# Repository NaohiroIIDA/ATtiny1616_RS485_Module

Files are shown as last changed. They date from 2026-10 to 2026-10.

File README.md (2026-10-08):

# ATtiny1616_RS485_Module

ATtiny1616マイコンとRS485トランシーバを搭載した小型の基板モジュールです。

## 概要

ATtiny1616とRS485トランシーバ（H485EIDQ）を13×22mmの基板に載せたモジュールです。
4ピンのJST SHコネクタで、複数台をRS485バスに数珠つなぎにできます。
空いているGPIOはすべて2.54mmピッチのピンヘッダに出してあります。

- **MCU**: ATtiny1616-MNR（QFN-20、tinyAVR 1-series）
- **通信**: RS485（半二重）
- **設計ツール**: EasyEDA Pro

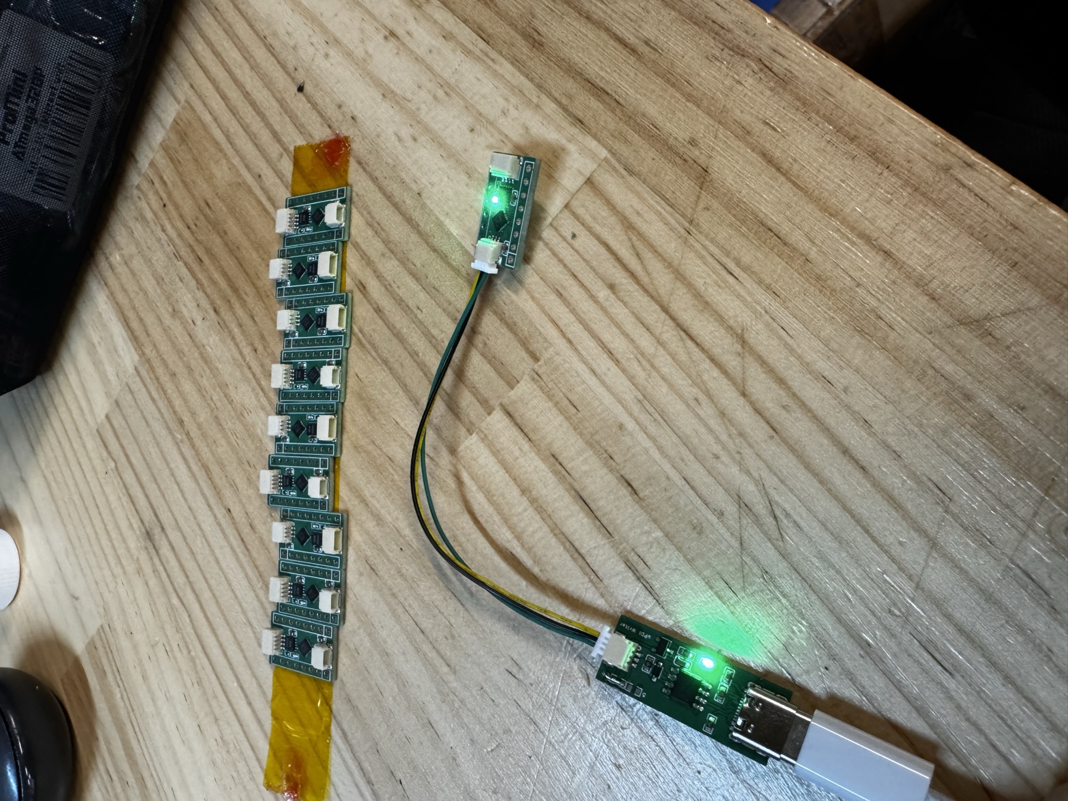
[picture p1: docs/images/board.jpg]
ATtiny1616 RS485 Module


*左：組み立て済みの基板。右：UPDIライタにつないで書き込んでいるところ*

## ハードウェア仕様

| 項目 | 内容 |
|---|---|
| MCU | ATtiny1616-MNR |
| RS485トランシーバ | H485EIDQ/TR（DFN-8） |
| 電源電圧 | 5V |
| 終端抵抗 | 120Ω（R6、裏面。標準では未実装） |
| 基板サイズ | 約13.2×21.8mm |
| RS485コネクタ | JST SM04B-SRSS-TB（SH 1.0mm 4ピン）。表面のU6と、裏面のU11（標準では未実装） |
| 書込みコネクタ | JST SM03B-SRSS-TB（SH 1.0mm 3ピン、UPDI）（U9） |
| GPIO | 2.54mmピッチ 8ピンヘッダ×2（H1・H2） |
| 状態LED | PB0（1kΩ経由、Highで点灯） |

### 裏面部品の実装（R6・U11）

裏面のR6（120Ω終端抵抗）とU11（2つ目のRS485コネクタ）は標準では未実装です。バス上のどこに置くかで、どちらか一方を実装します。

| 位置 | 実装する部品 |
|---|---|
| バスの末端 | R6（120Ω終端抵抗） |
| バスの途中（次のデバイスへつなぐ） | U11（コネクタ） |

```
[マスター]──U6[モジュール]U11──U6[モジュール]U11──U6[モジュール]R6
              （途中）              （途中）              （末端）
```

### MCUのピン割り当て

| ATtiny1616 | 機能 |
|---|---|
| PB2（TXD） | RS485 DI（送信） |
| PB3（RXD） | RS485 RO（受信） |
| PB4 | RS485 DE / RE#（送信イネーブル。Highで送信） |
| PB0 | LED（Highで点灯） |
| PA0 | UPDI |

RS485にはUSART0のデフォルトピン（PB2/PB3）を使っています。

### ピン一覧（Arduinoピン番号と周辺機能）

Arduinoピン番号はmegaTinyCoreの番号です。コードでは `PIN_PB0` のようにポート名で書くと、番号の取り違えを防げます。

| ピン | Arduino番号 | 基板での用途 | 主な周辺機能 |
|---|---|---|---|
| PA4 | 0 | H1-3 | ADC0 AIN4、SPI SS、PWM |
| PA5 | 1 | H1-4 | ADC0 AIN5、PWM |
| PA6 | 2 | H1-5 | ADC0 AIN6 |
| PA7 | 3 | H1-6 | ADC0 AIN7 |
| PB5 | 4 | H1-7 | ADC0 AIN8 |
| PB4 | 5 | RS485 DE / RE# | （使用中） |
| PB3 | 6 | RS485 RO | USART0 RX（使用中） |
| PB2 | 7 | RS485 DI | USART0 TX（使用中） |
| PB1 | 8 | H1-8 | ADC0 AIN10、I2C SDA（標準）、PWM |
| PB0 | 9 | LED | I2C SCL（標準）（LEDで使用中） |
| PC0 | 10 | H2-8 | SPI SCK（代替）、PWM |
| PC1 | 11 | H2-7 | SPI MISO（代替）、PWM |
| PC2 | 12 | H2-6 | SPI MOSI（代替） |
| PC3 | 13 | H2-5 | SPI SS（代替） |
| PA1 | 14 | H2-3 | ADC0 AIN1、SPI MOSI（標準）、I2C SDA（代替） |
| PA2 | 15 | H2-2 | ADC0 AIN2、SPI MISO（標準）、I2C SCL（代替） |
| PA3 | 16 | H2-1 | ADC0 AIN3、SPI SCK（標準）、PWM |
| PA0 | 17 | UPDI | （書き込み専用） |

PWMはmegaTinyCoreの標準設定で `analogWrite()` が使えるピンです。詳細はATtiny1616のデータシートで確認してください。

> **I2Cを使うときの注意**：I2C（TWI0）の標準ピンはSCL=PB0、SDA=PB1ですが、PB0はLEDにつながっています。I2Cは代替ピン（SCL=PA2、SDA=PA1）に切り替えて使ってください。megaTinyCoreでは `Wire.swap(1);` を `Wire.begin()` の前に呼びます。

### コネクタ

**RS485（U6・U11、2つとも同じピン配置）**

| ピン | 信号 |
|---|---|
| 1 | VCC |
| 2 | A |
| 3 | B |
| 4 | GND |

**UPDI（U9）**

| ピン | 信号 |
|---|---|
| 1 | UPDI |
| 2 | GND |
| 3 | VCC |

**H1**

| ピン | 1 | 2 | 3 | 4 | 5 | 6 | 7 | 8 |
|---|---|---|---|---|---|---|---|---|
| 信号 | GND | VCC | PA4 | PA5 | PA6 | PA7 | PB5 | PB1 |

**H2**

| ピン | 1 | 2 | 3 | 4 | 5 | 6 | 7 | 8 |
|---|---|---|---|---|---|---|---|---|
| 信号 | PA3 | PA2 | PA1 | UPDI | PC3 | PC2 | PC1 | PC0 |

## ファームウェア開発

| 項目 | 内容 |
|---|---|
| 開発環境 | PlatformIO（platform: `atmelmegaavr`、framework: `arduino`。コアはmegaTinyCore） |
| クロック | 20MHz（内部オシレータ。ヒューズOSCCFG=0x02） |
| 書き込み | SerialUPDI（U9コネクタ、57600bps） |

サンプル：

- [firmware/Blink_led](firmware/Blink_led)：状態LEDの点滅。新しいプロジェクトの雛形としても使えます

```bash
cd firmware/Blink_led
pio run                                                  # ビルド
pio run -t fuses  --upload-port /dev/cu.usbserial-XXXX   # ヒューズ書き込み（初回のみ）
pio run -t upload --upload-port /dev/cu.usbserial-XXXX   # 書き込み
```

ポート名は `pio device list` で確認できます。ヒューズを書き込まないと出荷時設定（16MHz）のまま動き、時間がずれます。

### ヒューズ設定

| ヒューズ | 値 | 内容 |
|---|---|---|
| WDTCFG（FUSE0） | 0x00 | ウォッチドッグ無効 |
| BODCFG（FUSE1） | 0x00 | BOD無効 |
| OSCCFG（FUSE2） | 0x02 | 20MHz |
| SYSCFG0（FUSE5） | 0xC4 | CRC無効、PA0=UPDI、チップ消去でEEPROMも消去 |
| SYSCFG1（FUSE6） | 0x06 | 起動待機時間 8ms |
| APPEND（FUSE7） | 0x00 | アプリ領域制限なし |
| BOOTEND（FUSE8） | 0x00 | ブートセクションなし |

> **警告**：SYSCFG0のRSTPINCFGを変更しないでください（例：`0xC8`）。PA0がUPDIからRESETや GPIOに切り替わり、通常のUPDIライタでは二度と書き込めなくなります。復旧には12V対応の高電圧UPDIライタが必要です。

## リポジトリ構成

```
hardware/
  schematic/   回路図（PDF）
  pcb/         EasyEDA Proプロジェクト（.epro2）、PCB図面
  gerber/      製造用Gerberファイル
  bom/         部品表（BOM）、部品配置（CPL）
  3d/          3Dモデル（STEP）
firmware/      サンプルファームウェア
docs/          ドキュメント、写真
```

## 基板データ

| ファイル | 置き場所 |
|---|---|
| 回路図PDF | `hardware/schematic/` |
| PCB図面PDF | `hardware/pcb/` |
| EasyEDA Proプロジェクト（.epro2） | `hardware/pcb/` |
| Gerber（zip） | `hardware/gerber/` |
| BOM（xlsx・csv） | `hardware/bom/` |
| 3Dモデル（STEP） | `hardware/3d/` |

.epro2は、EasyEDA Proの「ファイル → インポート」で開けます。

## 使用例

このモジュールは以下のプロジェクトで使っています。

- [KER_TLE_V3_Module](https://github.com/NaohiroIIDA/KER_TLE_V3_Module)：TLE5012B磁気角度センサーモジュール

## ライセンス

[MIT License](LICENSE)

回路図・基板データ・ファームウェアを含め、このリポジトリのすべてのファイルが対象です。著作権表示を残せば、商用・非商用を問わず自由に使用・改変・再配布できます。

## 作者

Naohiro IIDA

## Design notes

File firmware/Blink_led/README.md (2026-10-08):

# Blink_led

ATtiny1616 RS485モジュールの状態LED（PB0）を500ms間隔で点滅させるサンプルです。
RS485のDE/RE#（PB4）はLowにして、バスを駆動しないようにしています。

## ビルドと書き込み

このフォルダ（`firmware/Blink_led`）で実行します。

```bash
# ビルド
pio run

# ヒューズ書き込み（20MHz設定など。初回のみ）
pio run -t fuses --upload-port /dev/cu.usbserial-120

# 書き込み
pio run -t upload --upload-port /dev/cu.usbserial-120
```

ポート名は `pio device list` で確認してください（Windowsなら `COM4` など）。
書き込みはSerialUPDI（U9コネクタ）で行います。

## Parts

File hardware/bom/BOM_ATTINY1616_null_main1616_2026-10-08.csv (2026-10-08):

No. | Quantity | Comment | Designator | Footprint | Value | Manufacturer Part | Manufacturer | Supplier Part | Supplier
1 | 2 | 100nF | C1,C2 | C0603 | 100nF | CC0603KRX7R9BB104 | YAGEO(国巨) | C14663 | LCSC
2 | 2 | PZ254V-11-08P | H1,H2 | HDR-TH_8P-P2.54-V-M |  | PZ254V-11-08P | XFCN(兴飞) | C492407 | LCSC
3 | 1 | F.0402.00001/P2-0402G1TS2-045T-001 | LED1 | LED0402-R-RD_GREEN |  | F.0402.00001/P2-0402G1TS2-045T-001 | TUOZHAN(拓展光电) | C7496801 | LCSC
4 | 1 | 1kΩ | R5 | R0402 | 1kΩ | 0402WGF1001TCE | UNI-ROYAL(厚声) | C11702 | LCSC
5 | 1 | 120 | R6 | R0603 | 120
6 | 1 | ATTINY1616-MNR | U4 | QFN-20_L3.0-W3.0-P0.40-BL-EP1.7 |  | ATTINY1616-MNR | MICROCHIP(美国微芯) | C507118 | LCSC
7 | 2 | SM04B-SRSS-TB(LF)(SN) | U6,U11 | CONN-SMD_4P-P1.00_SM04B-SRSS-TB-LF-SN |  | SM04B-SRSS-TB(LF)(SN) | JST | C160404 | LCSC
8 | 1 | SM03B-SRSS-TB(LF)(SN) | U9 | CONN-SMD_SM03B-SRSS-TB-LF-SN-P |  | SM03B-SRSS-TB(LF)(SN) | JST | C160403 | LCSC
9 | 1 | H485EIDQ/TR | U10 | DFN-8_L3.0-W3.0-P0.65-BL-EP2.2 |  | H485EIDQ/TR | HGSEMI(华冠) | C46552321 | LCSC

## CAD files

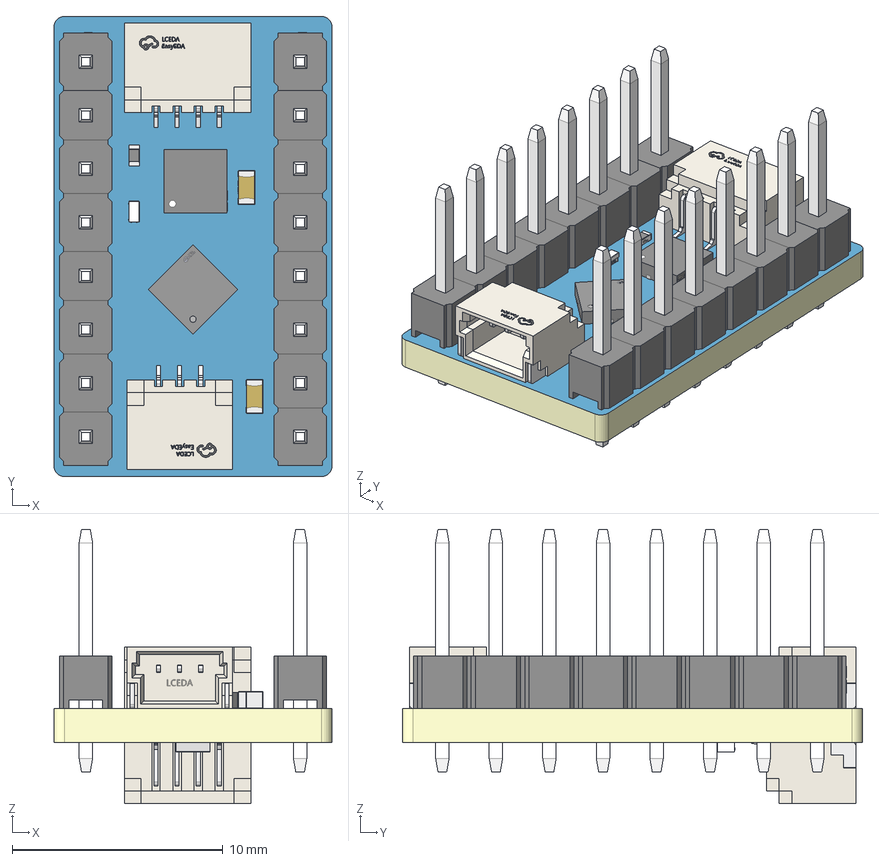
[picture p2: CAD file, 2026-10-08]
hardware/3d/3D_PCB9_2026-10-08.step
13.2 x 21.8 x 13.0 mm
Board~mkLh
TopCopper~mkLh
BottomCopper~mkLh
TopSilkscreen~mkLh
BottomSilkscreen~mkLh
TopFpcStiffener~mkLh
BottomFpcStiffener~mkLh
R0402~R0402_L1.0-W0.5-H0.4~IAVS
C0603~C0603_L1.6-W0.8-H0.8~PEQx x 2
CONN-SMD_4P-P1.00_SM04B-SRSS-TB-LF-SN~CONN-SMD_SR1.00-WS-4P~b4fu x 2
R0603~R0603~KfRT
HDR-TH_8P-P2.54-V-M~HDR-TH_8P-P2.54-V-M~K4U0 x 2
CONN-SMD_SM03B-SRSS-TB-LF-SN-P~CONN-SMD_SR1.00-WS-3P~Nkpu
DFN-8_L3.0-W3.0-P0.65-BL-EP2.2~DFN-8_L3.0-W3.0-P0.65-BL-EP2.2~bgaz
QFN-20_L3.0-W3.0-P0.40-BL-EP1.7~QFN-20_L3.0-W3.0-P0.40-BL-EP1.7~nTAD
LED0402-R-RD_GREEN~LED0402-R-RD_GREEN~S2Qn

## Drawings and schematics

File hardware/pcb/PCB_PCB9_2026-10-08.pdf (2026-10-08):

No. | Quantity | Comment | Designator | Footprint | Value | Manufacturer Part | Manufacturer | Supplier Part | Supplier
1 | 2 | 100nF | C1,C2 | C0603 | 100nF | CC0603KRX 7R9BB104 | YAGEO(国巨 ) | C14663 | LCSC
2 | 2 | PZ254V-11-0 8P | H1,H2 | HDR-TH_8P-P2.54-V-M | | PZ254V-11-0 8P | XFCN(兴飞 ) | C492407 | LCSC
3 | 1 | F.0402.0000 1/P2-0402G1 TS2-045T-00 1 | LED1 | LED0402-R-RD_GREEN | | F.0402.0000 1/P2-0402G1 TS2-045T-00 1 | TUOZHAN( 拓展光电 ) | C7496801 | LCSC
4 | 1 | 1k | R5 | R0402 | 1k | 0402WGF10 01TCE | UNI-ROYAL( 厚声 ) | C11702 | LCSC
5 | 1 | 120 | R6 | R0603 | 120
6 | 1 | ATTINY1616 -MNR | U4 | QFN-20_L3.0 -W3.0-P0.40-BL-EP1.7 | | ATTINY1616 -MNR | MICROCHIP( 美国微芯 ) | C507118 | LCSC
7 | 2 | SM04B-SRS S-TB(LF)(SN ) | U6,U11 | CONN-SMD_ 4P-P1.00_S M04B-SRSS-TB-LF-SN | | SM04B-SRS S-TB(LF)(SN ) | JST | C160404 | LCSC
8 | 1 | SM03B-SRS S-TB(LF)(SN ) | U9 | CONN-SMD_ SM03B-SRS S-TB-LF-SN- P | | SM03B-SRS S-TB(LF)(SN ) | JST | C160403 | LCSC
9 | 1 | H485EIDQ/T R | U10 | DFN-8_L3.0-W3.0-P0.65-BL-EP2.2 | | H485EIDQ/T R | HGSEMI( 华 冠 ) | C46552321 | LCSC

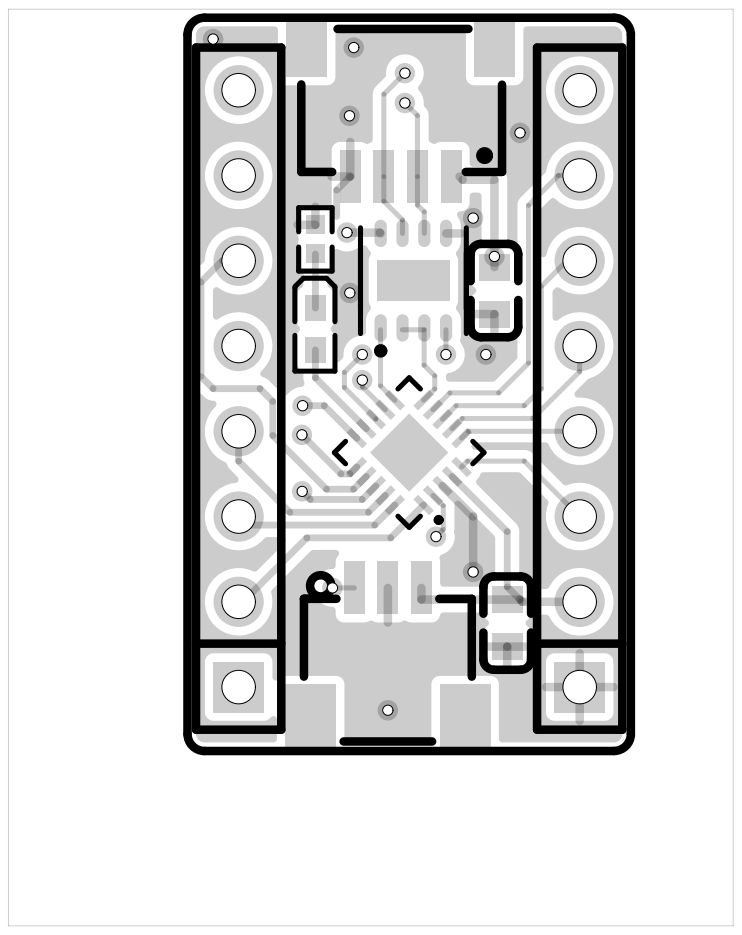
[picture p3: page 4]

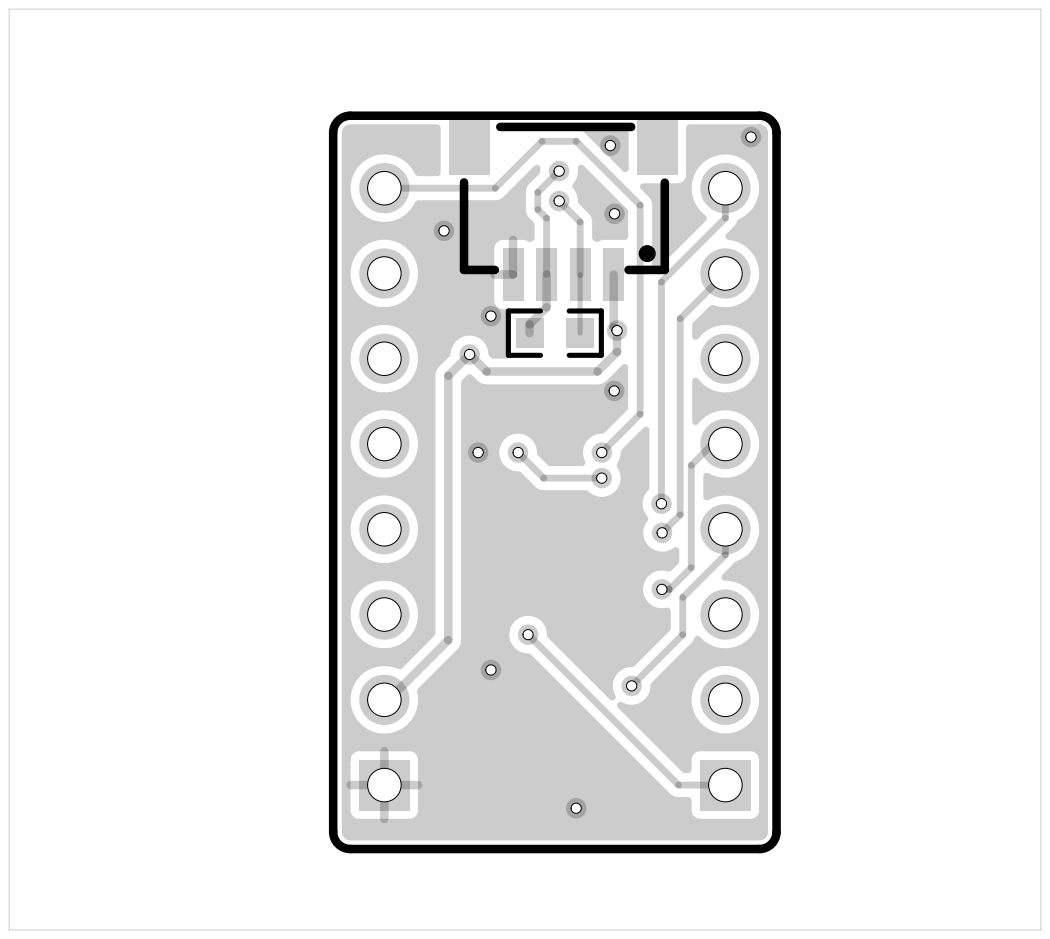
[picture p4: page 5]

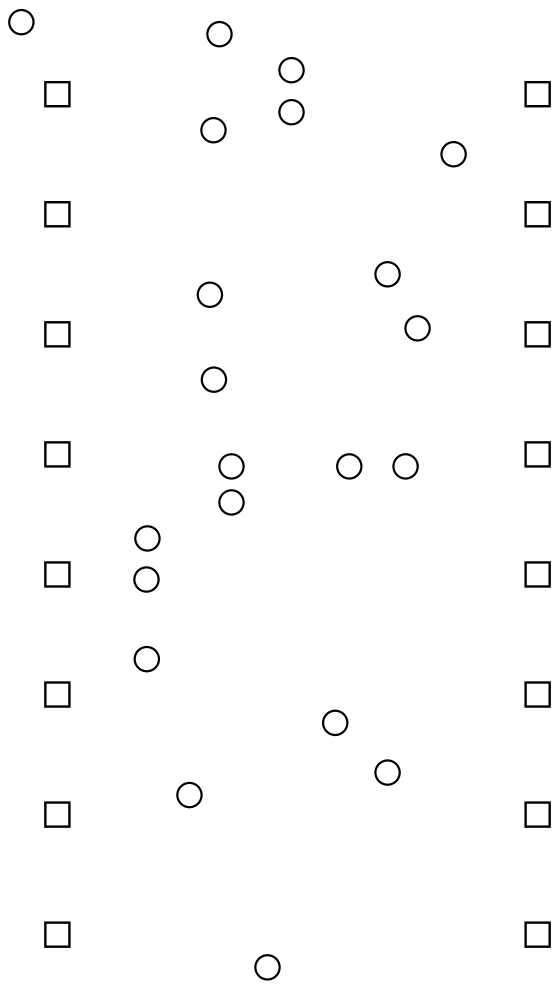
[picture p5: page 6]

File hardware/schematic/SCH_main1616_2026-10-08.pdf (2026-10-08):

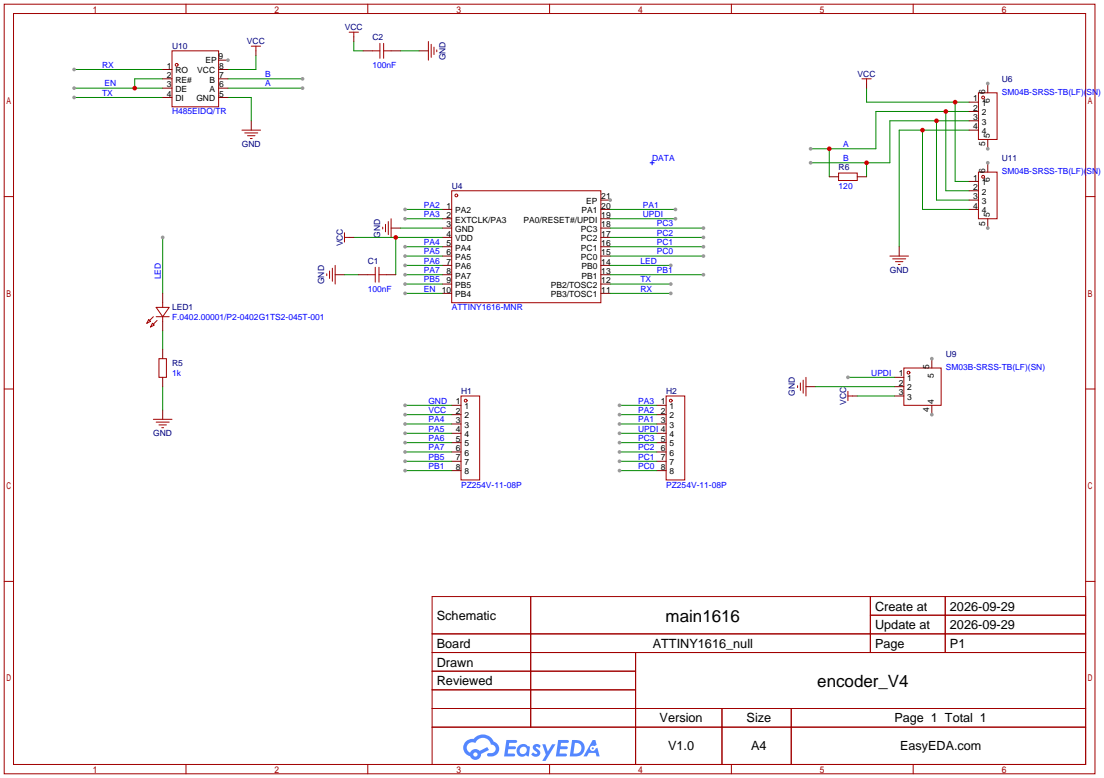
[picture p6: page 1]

SM03B-SRSS-TB(LF)(SN)

Schematic | main1616 | Create at | 2026-09-29

Update at | 2026-09-29

Board | ATTINY1616_null | Page | P1
Drawn | | encoder_V4
Reviewed

Version | Size | Page 1 Total 1
V1.0 | A4 | EasyEDA.com

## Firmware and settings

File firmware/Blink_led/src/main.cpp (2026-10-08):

#include <Arduino.h>

// ATtiny1616 RS485 Module - Blink_led
// 状態LED（PB0）を500msごとに点滅させる

#define LED      PIN_PB0   // 状態LED（1kΩ経由）
#define RS485_DE PIN_PB4   // RS485 DE / RE#（Highで送信）

#define BLINK_INTERVAL_MS 500

void setup() {
  // RS485ドライバは無効（受信状態）にしておき、バスを駆動しない
  pinMode(RS485_DE, OUTPUT);
  digitalWrite(RS485_DE, LOW);

  pinMode(LED, OUTPUT);
}

void loop() {
  digitalWrite(LED, HIGH);
  delay(BLINK_INTERVAL_MS);
  digitalWrite(LED, LOW);
  delay(BLINK_INTERVAL_MS);
}

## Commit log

2026-10-08 Add EasyEDA Pro hardware files and fill in README specs
    [3D_PCB9_2026-10-08.step, BOM_ATTINY1616_null_PCB9_2026-10-08.xlsx]
2026-10-08 Document 5V supply and bottom-side R6/U11 population; add CSV BOM
    [BOM_ATTINY1616_null_main1616_2026-10-08.csv]
2026-10-08 Add board photo to README
2026-10-08 Add Blink_led PlatformIO sample firmware
2026-10-08 Document firmware setup, fuses, pin functions and LED polarity in README
    - Add firmware development section (PlatformIO/megaTinyCore, 20MHz, SerialUPDI)
    - Add fuse table with warning against changing RSTPINCFG
    - Add full pin table with Arduino pin numbers and peripheral functions
    - Note I2C default SCL conflicts with LED (PB0); use alternate pins
    - State LED is active High
    - Fix fuse numbers in Blink_led platformio.ini comments
